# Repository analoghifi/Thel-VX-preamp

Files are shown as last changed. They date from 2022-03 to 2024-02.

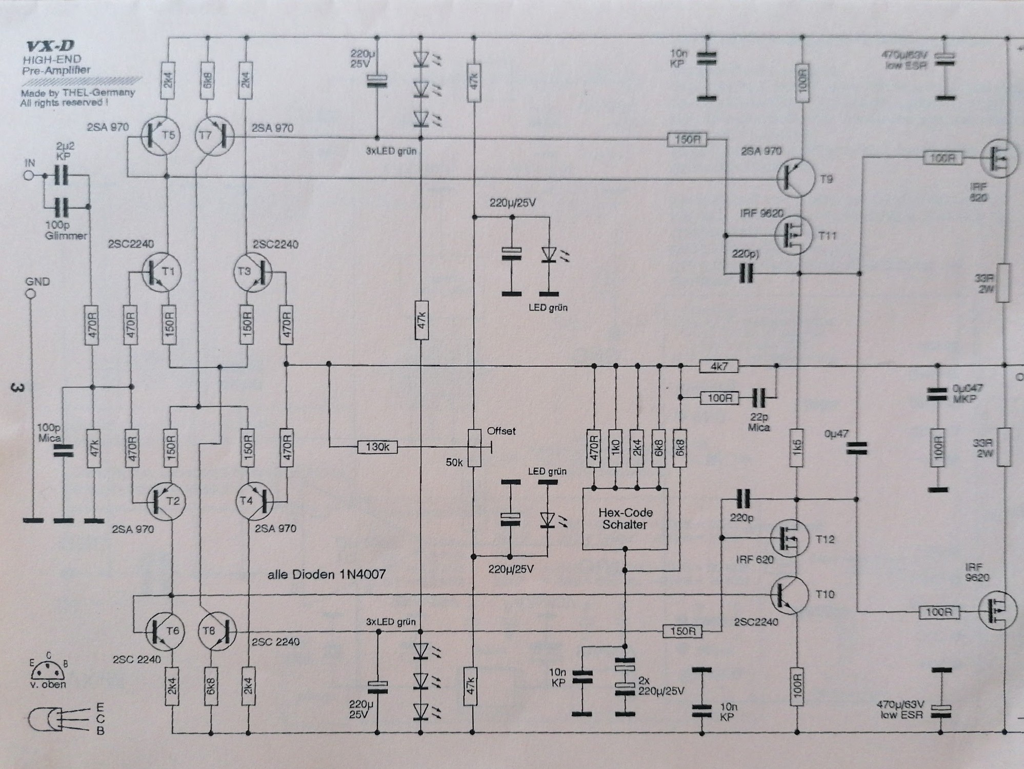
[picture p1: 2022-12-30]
VX-D/docs/german/VX-D_Schematic.jpg

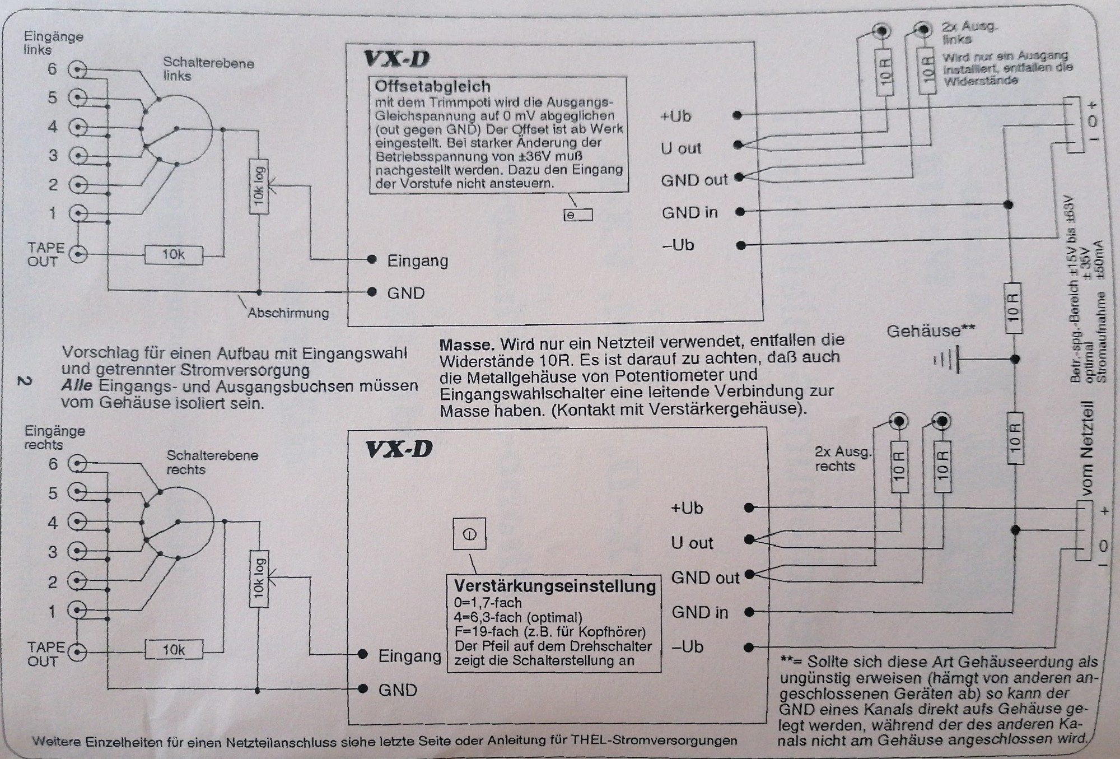
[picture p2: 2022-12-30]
VX-D/docs/german/VX-D_wiring.jpg

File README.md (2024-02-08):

### "VX-D" (2007 - 2016):  
* fully discrete circuit (all transistors / no OP-Amps)
* single ended input
* single ended output
* AC coupled input (with film/foil input cap)
* MOSFET Class-A output
* very low-impedance output / is able to drive 1W @ 8Ω (8Ω short-term / 22Ω permanently)
* adjustable gain (16 steps)
* can also be used very well as a "high-end" headphone amplifier
* operating voltage min./max.: ±9V .. ±63V (optimum: ±24V .. ±36V)
  
https://web.archive.org/web/20070809231533/http://www.thel-audioworld.de/module/VXD/vxd.htm  
https://web.archive.org/web/20160325140821/http://thel-audioworld.de/module/VXD/vxd.htm  
<hr>  

### "VX-Line" (from 03/2017):  
* OP-Amp input stage (LME 49720)
* balanced input
* single ended output
* DC coupled
* MOSFET Class-A output (itegrated into the OP-Amps feedback loop)
* very low-impedance output / is able to drive 1W @ 8Ω (8Ω short-term / 22Ω permanently)
* adjustable gain (5 steps)
* can also be used very well as a "high-end" headphone amplifier
* operating voltage min./max.: ±9V .. ±35V (optimum: ±18V .. ±24V)
  
https://web.archive.org/web/20170523101631/http://www.thel-audioworld.de/module/VX-Line/vx-line.htm  
https://web.archive.org/web/20210514101836/http://thel-audioworld.de/module/VX-Line/vx-line.htm  
  
2 different generations of PCB:  
* 2017 - 2020
* from 2021
  
----  
### Kicad projects in this repo:  
* [VX-Line_2021__original](https://github.com/analoghifi/Thel-VX-preamp/tree/main/VX-Line/hardware/KiCad/VX-Line_2021__original) | state: initial release v1.01 | like the original, 1-layer, THT
* [VX-D_original](https://github.com/analoghifi/Thel-VX-preamp/tree/main/VX-D/hardware/KiCad/VX-D_original) | state: coming soon... | like the original, 1-layer, THT

----

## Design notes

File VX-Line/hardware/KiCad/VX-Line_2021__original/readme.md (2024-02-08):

this is not the original Thel PCB but it's very like\* the original with the following exceptions:  
* more massive ground and power supply PCB tracks  
* using a combined 2.5mm/5.0mm pin spacing footprint for the small ceramic caps (C1,C2,C3,C11)  
  
\*(same schematic / same board dimensions / same 1-layer\** layout THT / same THT components in the same places on the board)  
\**(strictly speaking, this KiCad PCB is a two-layer PCB with plated-through holes, but you can also (let) produce it as a classic 1-layer PCB with non-plated holes if you wish, since all the tracks are on the bottom side only)  

----  

### remarks:  
#### U1:  
instead of [LME49720](https://www2.mouser.com/ProductDetail/Texas-Instruments/LME49720NA-NOPB?qs=7lkVKPoqpbYtIqwyg5iDaA%3D%3D) you can use [LM4562](https://www2.mouser.com/ProductDetail/Texas-Instruments/LM4562NA-NOPB?qs=QbsRYf82W3Gc2w4DLq%252BZjw%3D%3D) (both Texas Instruments),  
these two are 100% identical (even regarding their inner guts).
  
----  

these are KiCad 6.x projects  
see how to get the proper 3D-Models from here: https://github.com/analoghifi/KiCad-3D-Models  

use kicanvas.org to see this KiCad-Project in your browser:  
https://kicanvas.org/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

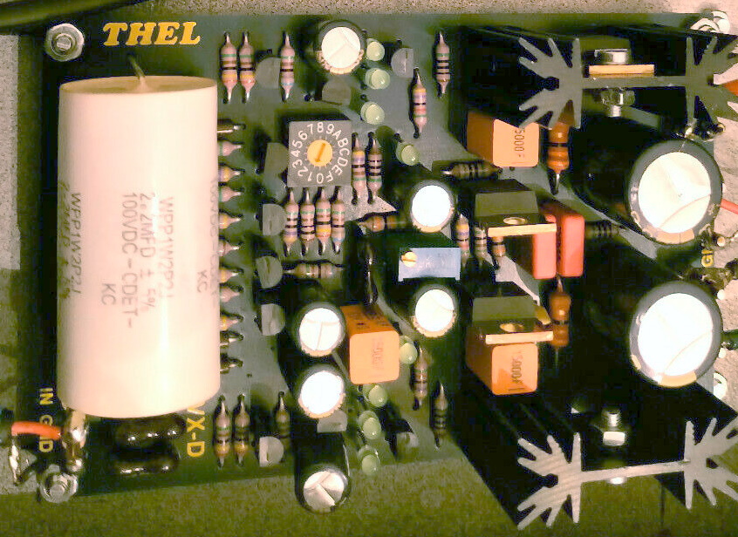
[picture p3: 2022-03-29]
VX-D/hardware/VX-D_1.jpg

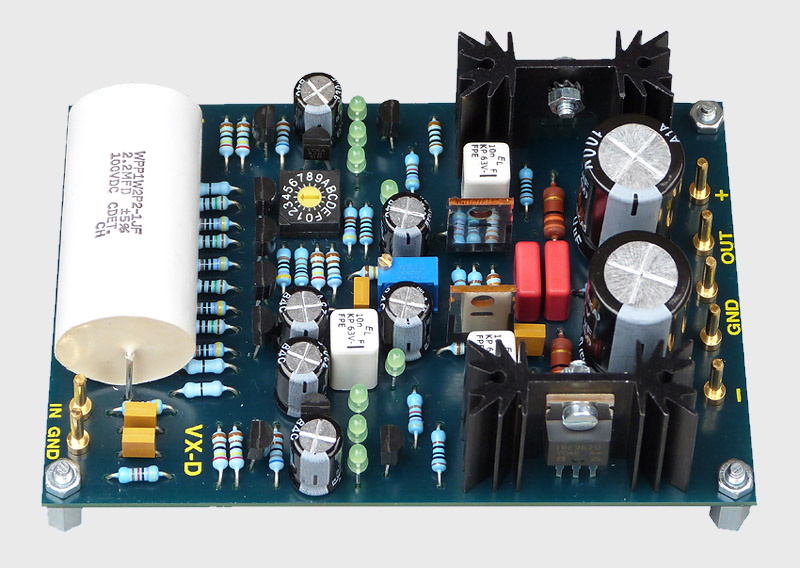
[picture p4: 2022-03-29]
VX-D/hardware/VX-D__2007-2016.jpg

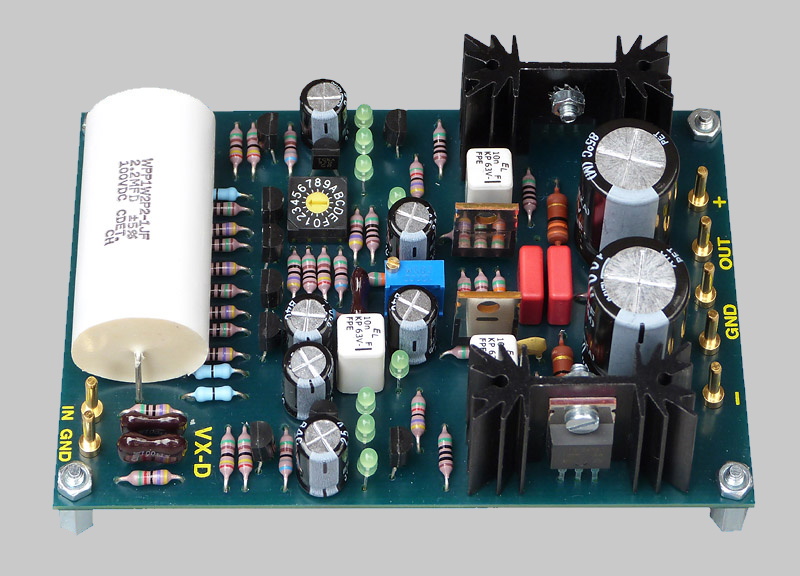
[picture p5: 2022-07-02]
VX-D/hardware/VXDw1.jpg

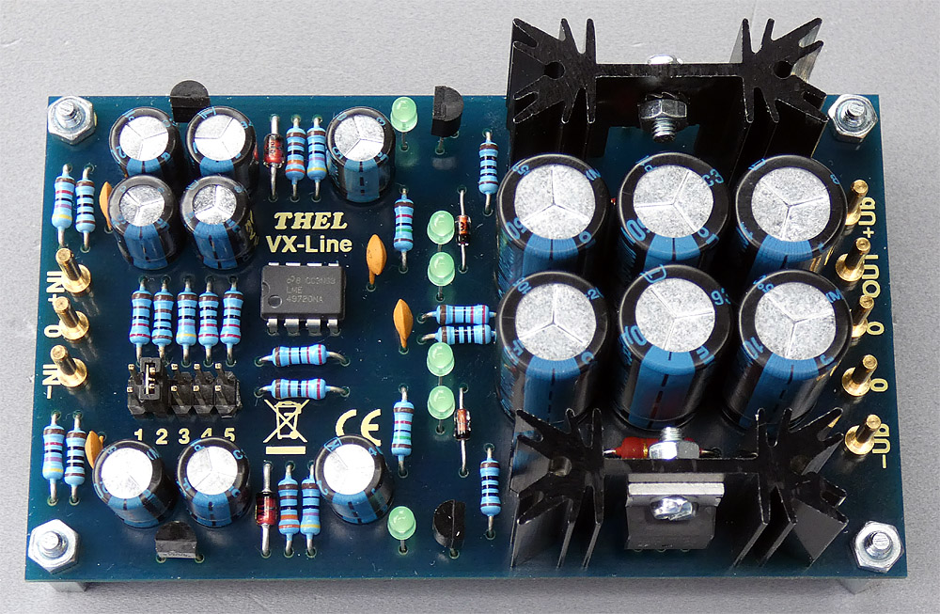
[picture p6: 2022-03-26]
VX-Line/hardware/VX-Line_2021.jpg

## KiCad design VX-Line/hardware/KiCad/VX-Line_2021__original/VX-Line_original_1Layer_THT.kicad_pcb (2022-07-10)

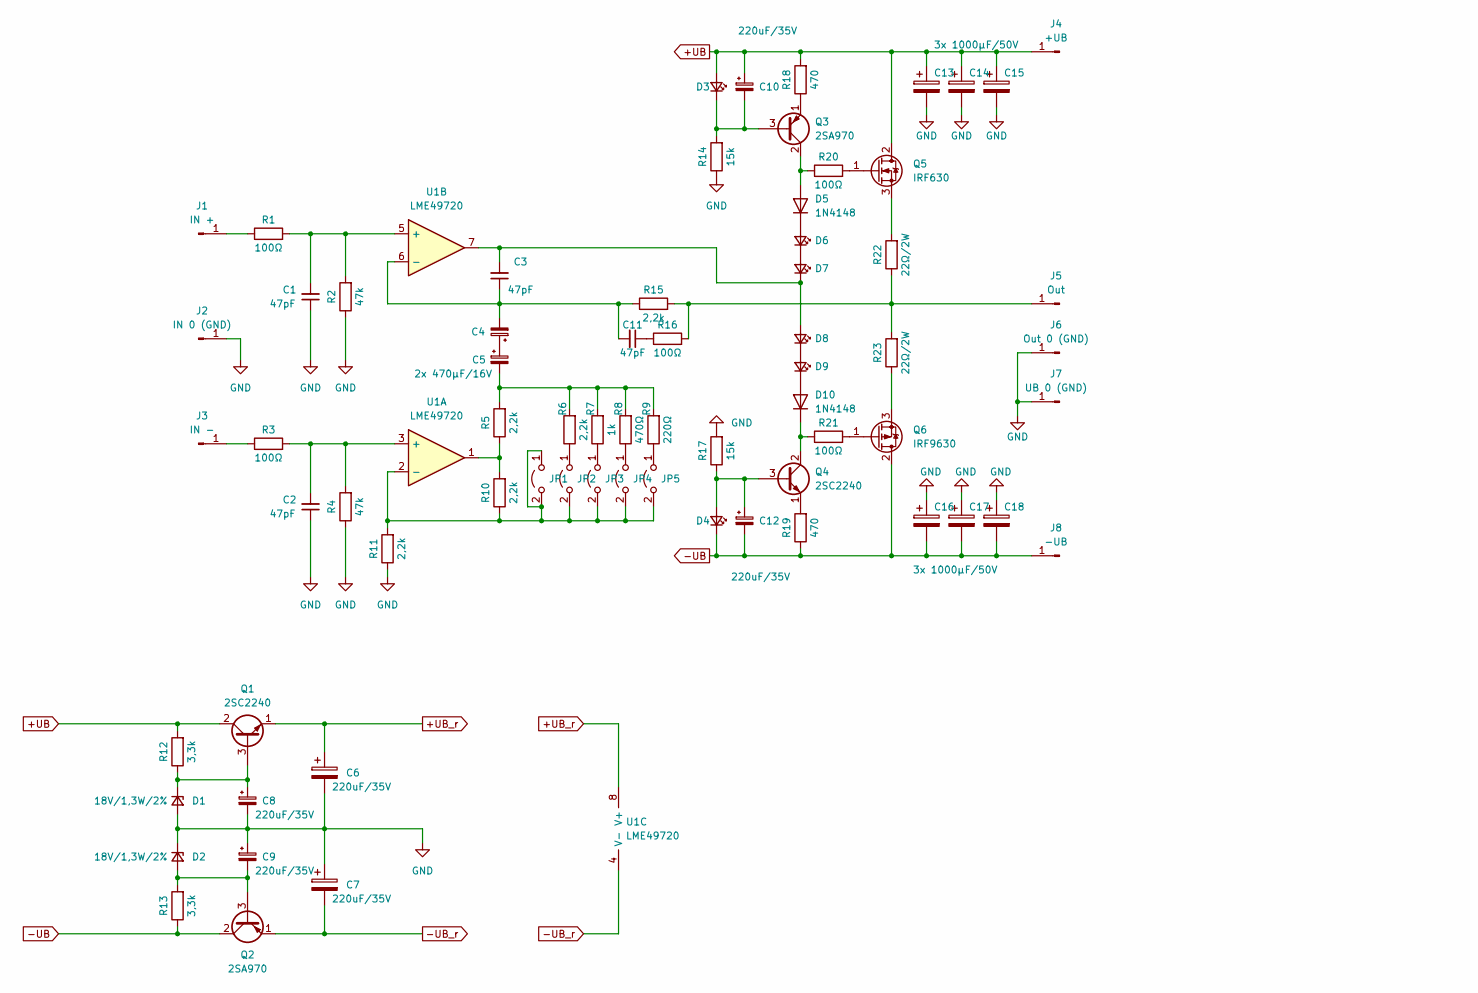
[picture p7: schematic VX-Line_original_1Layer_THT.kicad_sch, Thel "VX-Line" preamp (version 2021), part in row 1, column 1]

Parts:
C1, C2, C3, C11: 47pF; C_Rect_L7.0mm_W2.5mm_P2.50_5.00mm_min_silk
C4: 2x 470µF/16V; CP_Radial_Black_D8.2mm_H12.0mm_P3.50mm_minimal_silk
C5: 470µF/16V; CP_Radial_Black_D8.2mm_H12.0mm_P3.50mm_minimal_silk
C6, C7, C8, C9, C10, C12: 220uF/35V; CP_Radial_Black_D8.2mm_H12.0mm_P3.50mm_minimal_silk
C13, C16: 3x 1000µF/50V; CP_Radial_Black_D13.0mm_H26.0mm_P5.00mm_minimal_silk
C14, C15, C17, C18: 1000µF/50V; CP_Radial_Black_D13.0mm_H26.0mm_P5.00mm_minimal_silk
D1, D2: 18V/1,3W/2%; D_DO-41_SOD81_P10.16mm_Horizontal_minSilk
D3, D4: LED_Small; LED_D3.0mm_wide
D5, D10: 1N4148; Diode_L6.3mm_D2.5mm_P10.16mm_Horizontal_minSilk
D6, D7, D8, D9: LED_Small; LED_D3.0mm
J1: IN +; Loet_Pin_D1.5mm_L14.0mm
J2: IN 0 (GND); Loet_Pin_D1.5mm_L14.0mm
J3: IN -; Loet_Pin_D1.5mm_L14.0mm
J4: +UB; Loet_Pin_D1.5mm_L14.0mm
J5: Out; Loet_Pin_D1.5mm_L14.0mm
J6: Out 0 (GND); Loet_Pin_D1.5mm_L14.0mm
J7: UB 0 (GND); Loet_Pin_D1.5mm_L14.0mm
J8: -UB; Loet_Pin_D1.5mm_L14.0mm
JP1, JP2, JP3, JP4, JP5: Jumper_2_Open; PinHeader_1x02_P2.54mm_Vertical
Q1, Q4: 2SC2240; TO-92_wide
Q2, Q3: 2SA970; TO-92_wide
Q5: IRF630; TO-220-3_Vertical
Q6: IRF9630; TO-220-3_Vertical
R1, R3, R20, R21: 100Ω; R_Axial_DIN0207_L6.3mm_D2.5mm_P10.16mm_Horizontal_minSilk
R2, R4: 47k; R_Axial_DIN0207_L6.3mm_D2.5mm_P10.16mm_Horizontal_minSilk
R5, R6, R10, R11: 2,2k; R_Axial_DIN0207_L6.3mm_D2.5mm_P10.16mm_Horizontal_minSilk
R7: 1k; R_Axial_DIN0207_L6.3mm_D2.5mm_P10.16mm_Horizontal_minSilk
R8: 470Ω; R_Axial_DIN0207_L6.3mm_D2.5mm_P10.16mm_Horizontal_minSilk
R9: 220Ω; R_Axial_DIN0207_L6.3mm_D2.5mm_P10.16mm_Horizontal_minSilk
R12, R13: 3,3k; R_Axial_DIN0207_L6.3mm_D2.5mm_P10.16mm_Horizontal_minSilk
R14, R17: 15k; R_Axial_DIN0207_L6.3mm_D2.5mm_P10.16mm_Horizontal_minSilk
R15: 2,2k; R_Axial_Short_L6.3mm_D2.5mm_P9.0mm_Horiz_minSilk
R16: 100Ω; R_Axial_Short_L6.3mm_D2.5mm_P9.0mm_Horiz_minSilk
R18, R19: 470; R_Axial_DIN0207_L6.3mm_D2.5mm_P10.16mm_Horizontal_minSilk
R22, R23: 22Ω/2W; R_Axial_DIN0411_L9.9mm_D3.6mm_P12.70mm_Horizontal
U1: LME49720; DIP-8_W7.62mm

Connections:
+UB: C10.1, C13.1, C14.1, C15.1, D3.2 (A), J4.1, Q1.2 (C), Q5.2 (D), R12.2, R18.2
+UB_r: C6.1, Q1.1 (E), U1.8 (V+)
-UB: C12.2, C16.2, C17.2, C18.2, D4.1 (K), J8.1, Q2.2 (C), Q6.2 (D), R13.1, R19.1
-UB_r: C7.2, Q2.1 (E), U1.4 (V-)
GND: C1.1, C2.1, C6.2, C7.1, C8.2, C9.1, C13.2, C14.2, C15.2, C16.1, C17.1, C18.1, D1.2 (A), D2.1 (K), J2.1, J6.1, J7.1, R2.1, R4.1, R11.1, R14.1, R17.2
unnamed: C1.2, R1.2, R2.2, U1.5 (+)
unnamed: C2.2, R3.2, R4.2, U1.3 (+)
unnamed: C3.2, D7.1 (K), D8.2 (A), U1.7
unnamed: C4.1, C5.1
unnamed: C5.2, R5.2, R6.2, R7.2, R8.2, R9.2
unnamed: C8.1, D1.1 (K), Q1.3 (B), R12.1
unnamed: C9.2, D2.2 (A), Q2.3 (B), R13.2
unnamed: C10.2, D3.1 (K), Q3.3 (B), R14.2
unnamed: C11.1, R16.1
unnamed: C3.1, C4.2, C11.2, R15.1, U1.6 (-)
unnamed: C12.1, D4.2 (A), Q4.3 (B), R17.1
unnamed: D5.1 (K), D6.2 (A)
unnamed: D5.2 (A), Q3.2 (C), R20.1
unnamed: D6.1 (K), D7.2 (A)
unnamed: D8.1 (K), D9.2 (A)
unnamed: D10.1 (K), Q4.2 (C), R21.1
unnamed: D9.1 (K), D10.2 (A)
unnamed: J1.1, R1.1
unnamed: J3.1, R3.1
unnamed: J5.1, R15.2, R16.2, R22.1, R23.2
unnamed: JP1.1 (A), JP1.2 (B), JP2.2 (B), JP3.2 (B), JP4.2 (B), JP5.2 (B), R10.1, R11.2, U1.2 (-)
unnamed: JP2.1 (A), R6.1
unnamed: JP3.1 (A), R7.1
unnamed: JP4.1 (A), R8.1
unnamed: JP5.1 (A), R9.1
unnamed: Q3.1 (E), R18.1
unnamed: Q4.1 (E), R19.2
unnamed: Q5.1 (G), R20.2
unnamed: Q5.3 (S), R22.2
unnamed: Q6.1 (G), R21.2
unnamed: Q6.3 (S), R23.1
unnamed: R5.1, R10.2, U1.1

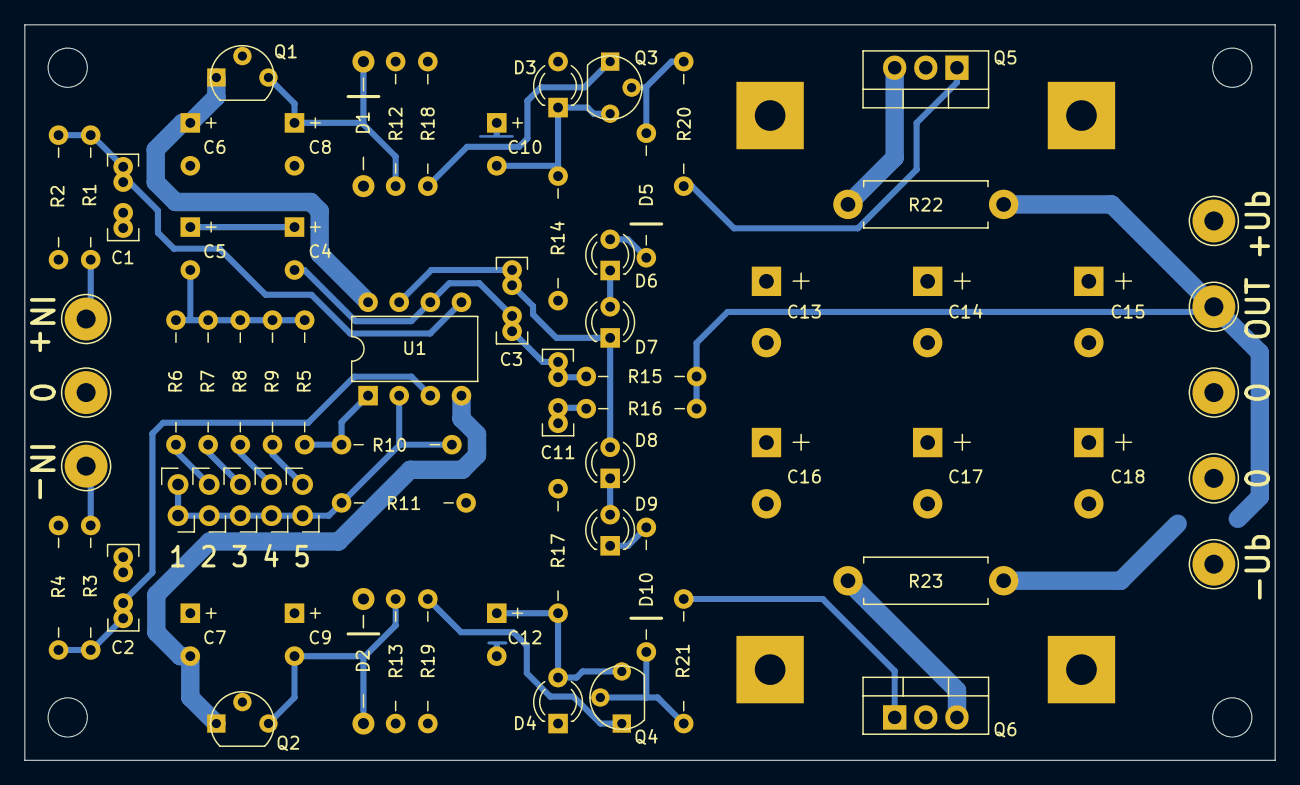
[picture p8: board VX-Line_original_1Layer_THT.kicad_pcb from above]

Board: 2 copper layers, 102.0 x 60.0 mm, 71 parts (0 on the bottom side), 37 nets.
